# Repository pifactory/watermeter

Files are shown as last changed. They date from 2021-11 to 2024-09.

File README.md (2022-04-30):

# Smart Water Meter Sensor
 [][cc-by]

Design files for making inductive sensor for reading out smart water meters.

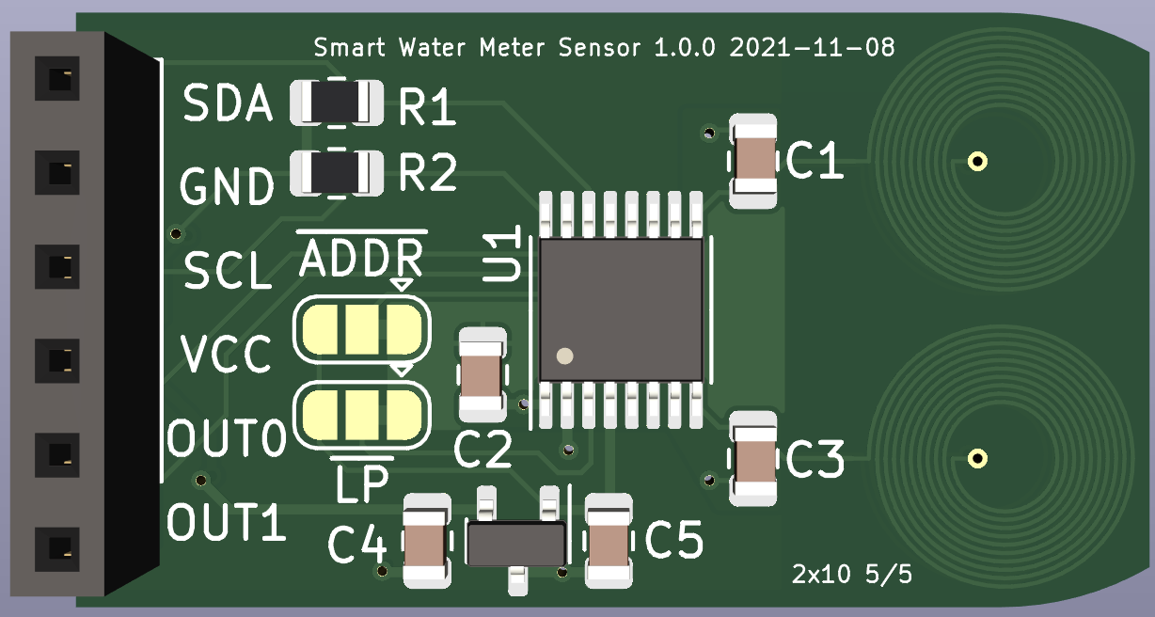
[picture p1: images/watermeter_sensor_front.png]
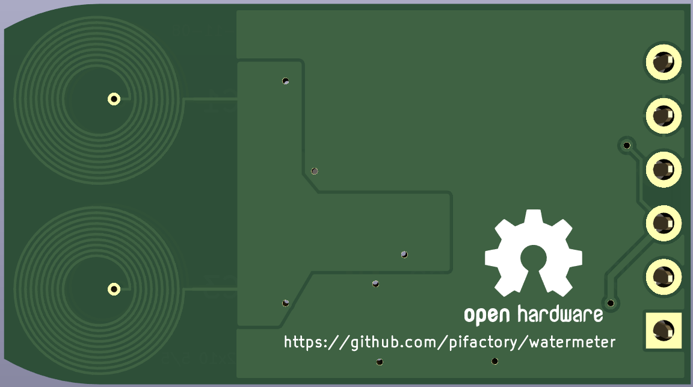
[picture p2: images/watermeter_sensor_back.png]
 

## Features

* 20 &mu;A in low-power mode (including microcontroller)
* Small footprint: 18mm x 32.5 mm, can be placed directly on the water meter glass
* Easy to use: inductive sensors are printed directly on the PCB
* Designed for wheel diameter of 18mm
* Includes 2 inductive sensors for reliable counting of the wheel turns

## How Smart Water Meter works

Many water meters are made 'smart-ready', ie they include a wheel under the glass
which makes 1 turn per liter. Half of the wheel contains some metal (copper) on it
which can be sensed by an inductive sensor.

Because of the costs water supply companies usually do not install smart reading device
on such meters, but some nerds among us are stubborn enough to design and install
their own reading device. Just to know how much water is used and be able to monitor it
with, say, a Home Assistant. It can be also used to detect leaks.

One inductive sensor is not enough for reliable readings. There are some corner
cases when the sensor will miss a turn of the wheel or count 1 turn 2 times. Think of it like
this: wheel can stop at any moment at any angle and then continue movement at any
time later on. During this stop environment can change significantly (temperature &
humidity) to fool the sensing circuit. On top of it, to save power, each inductive
sensor is scanned once in 800ms, ie there is no continous output from it. All in all,
2 inductive sensors allow to detect illogical readings and in many cases repair them.

For now here is just the sensor, controller is coming soon... I've made one for
Zigbee already and it runs on 2 AAA batteries.

Here is the photo of the first prototype:

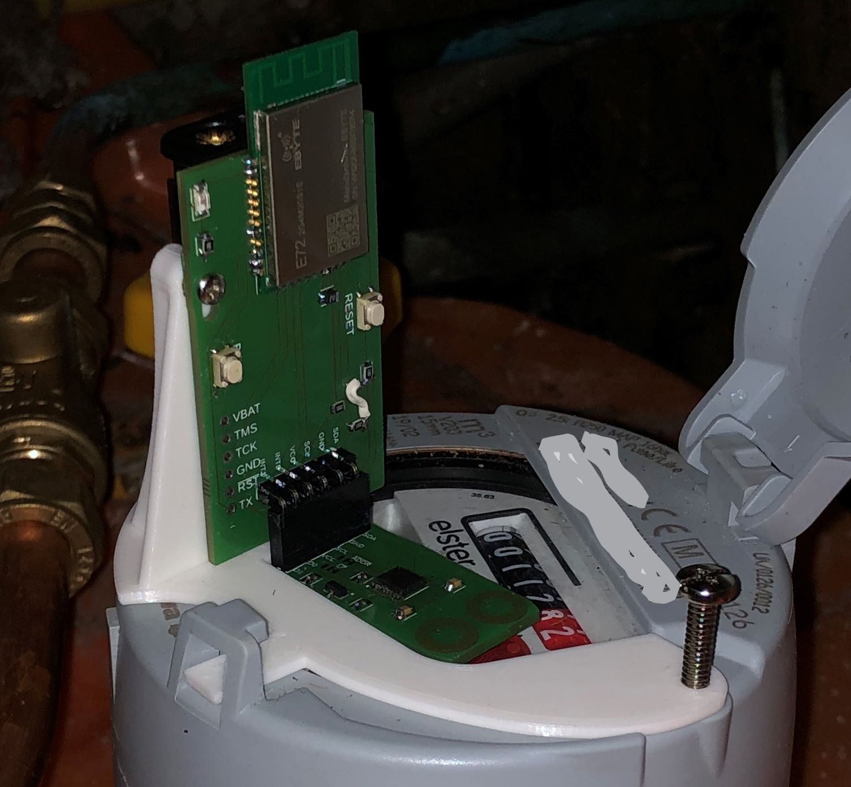
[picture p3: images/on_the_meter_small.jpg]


## How to use design files

I used KiCAD 6 to make the design. You will probably also want to install [kicad-goodies](https://github.com/pifactory/kicad-goodies) libraries, but this is not required.

A word about choosing a PCB shop. Inductive sensors on the PCB require as much as possible turns
on as little space possible. This means that the traces have to be as thin as possible and the
spacing between them has to be as small as possible. Also there is no copper around them +
geometry of the traces = you might get shorts between traces if you push it to the limit.

Most shops out there (including JLCPCB) claim to be able to produce 6 mils traces with 6 mils spacing
between them. I work with AISLER and they produce 5/5 mils boards for the same price,
so this design has 5/5 PCB coils. I've made 6/6 PCB coils available in 
[kicad-goodies](https://github.com/pifactory/kicad-goodies), you can try them if 5/5
coils will not work for you. AISLER will need just *.kicad_pcb file, no Gerber is needed there and therefore not provided in this repo.

## Zigbee Microcontroller

This repo has all you need to make a Zigbee microcontroller for the sensor:

* KiCAD 6 design files for the PCB (incl schematic)
* Compiled firmware
* Configuration file for Zigbee2MQTT

Microcontroller is based on EBYTE module with CC2652P.  

Firmware has following features:

* Low power, should work for years on 2 AAA batteries
* Water usage data is buffered for 5 minutes
* When parent connection is lost: try to rejoin every 5 minutes
* Transmit power is set to 14dBm, this should be enough to get signal in challenging RF situations and yet to not use too much battery

Because of a bug in TI software, rejoin period cannot be longer than 5 minutes. Also rejoin uses more power than standard data report, so try to avoid situations when device stays on for longer periods without a connection to the network (like days, weeks, months)

Operation with 2 buttons and 1 LED:
* Join new network: click BTN1
* Leave network: press BTN1 for at least 10 seconds and release the button (long click)
* Immediately send data (when part of the network): click BTN1
* Rejoin (when parent is lost): click BTN1
* RESET button restarts the device
* LED blink once device (re-)joins Zigbee network

### Zigbee2MQTT

Place provided `pifactory_watermeter.js` file in the same directory as `configuration.yaml` file.

Add these lines to `configuration.yaml` file:

```yaml
external_converters:
    pifactory_watermeter.js
```

Restart Zigbee2MQTT and join the device

## Holder

I've made a holder which fits my Elster water meter. Meter without sensor looks like this:

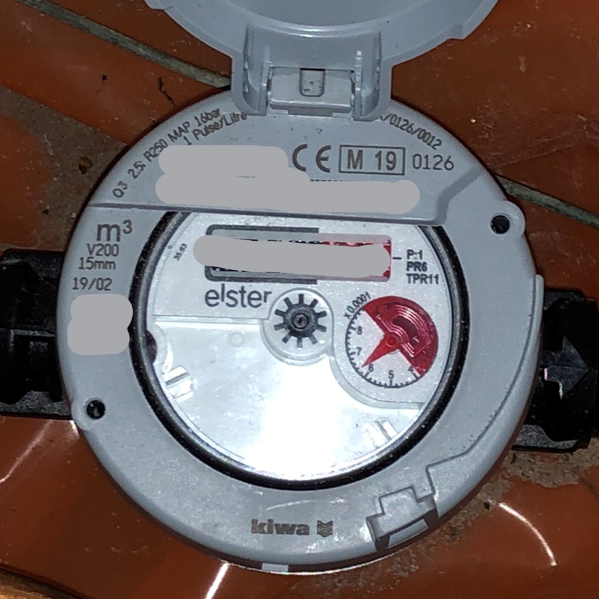
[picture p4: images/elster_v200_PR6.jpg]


I didn't tried the holder on any other meter, but I suspect it fits different models as well. Please share your meters/holders or contact me if you need help fitting this sensor to your meter.

---
This work is licensed under a
[Creative Commons Attribution 4.0 International License][cc-by].

[][cc-by]

[cc-by]: http://creativecommons.org/licenses/by/4.0/
[cc-by-image]: https://i.creativecommons.org/l/by/4.0/88x31.png
[cc-by-shield]: https://img.shields.io/badge/License-CC%20BY%204.0-lightgrey.svg

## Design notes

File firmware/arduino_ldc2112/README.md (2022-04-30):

# Example Arduino code for LDC2112 based water meter sensor

Small Platformio project to start making your own firmware for LDC2112 based water meter.

## This is just a demo

You have to add WiFi logic yourself and add data collection mechanism of choice (MQTT?) to connect it to your home automation platform.

## Known Issues

### GPIO interrupts do not trigger properly

Keep in mind that LDC2112 works from 1.8V and not 3.3V. This means that you get only 1.6-ish volts on interrupt lines coming from the chip. On most ESP-based boards I have in my possession this is not enough for reliable triggering of GPIO inputs.

There are 2 solutions:

*  Use i2c registers (like in this demo)
*  Make level translator `1.8V` --> `3.3V` (and enjoy `attachInterrupt(...)`)

### Sensor becomes blind when wheel stops under the coil for too long

LDC2112 is designed for inductive keyboard and has number of algorythms to reliably detect key press. One of them - baseline tracking. So, the chip detects rapid changes of inductance of the coil. When wheel stops or is moving too slowly, sensor can become 'blind'.

Best strategies to apply:
* Stop tracking baseline when the channel is active (wheel is under the coil)
* Change the speed of baseline tracking: slow for positive values, fast for negative
* Use both coils to detect movement. Baseline is tracked independently for each of them, so the chance that both become blind at the same time is low
* Define some mitigation measures once inconsistent triggering detected (coils trigger out of natural order):
  * Read status register (0x00) - this will clear TIMEOUT flag, or any other error flags
  * Temporarily enable full baseline tracking on misbehaving coil - may be it is just way off environment changes?

I advice also logging STATUS, OUT, DATA0 and DATA1 registers (0x00 - 0x05) when debugging this issue. Might give new insights on how further improve the algorythm.

### Reading is not 100% reliable

I've got it as far as 0.1% error of the actual value read on the meter itself, this is after 6 months. By no means statistically significant, just give you an idea.

That said, water meter reading via inductive sensor is not 100% reliable by design. Wheel on the water meter can be as slow or as fast as:
* I have 20l/min capacity on my home water supply, so full turn takes at least 3 seconds
* leaking water: wheel moves as slowly as you can imagine ([Parmenides](https://en.wikipedia.org/wiki/Philosophy_of_motion))
* No movement

The latter 2 are difficult to distinguish from slowly changing environment conditions, like temperature and humidity. What sensor sees is only slow change of induction, but there is no way to see why it is changing.

Both scan rate and sensitivity should not allow for undetected turns. The challenge here is that the wheel can stop at **any** position and the coils are sensed only so often by the chip. So, we can get stroboscope effect: like there is a movement, but it is not detected, because the wheel is moving too fast through the coil sensing zone and stops in the blind zone.

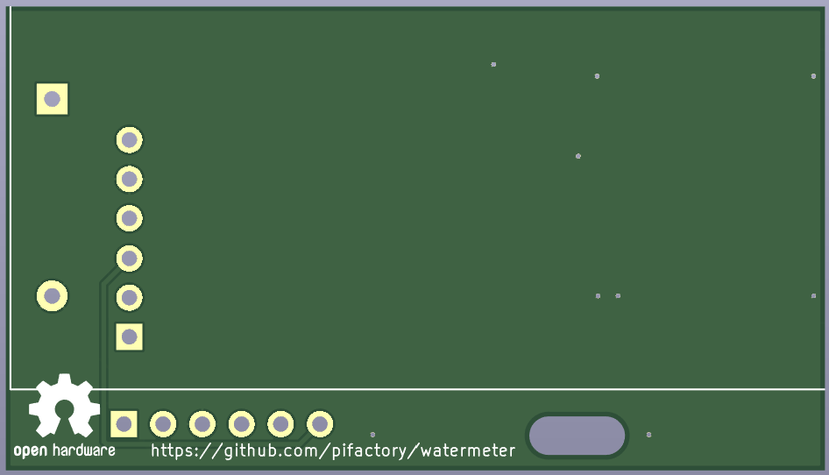
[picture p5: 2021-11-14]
images/watermeter_zigbee_mc_back.png

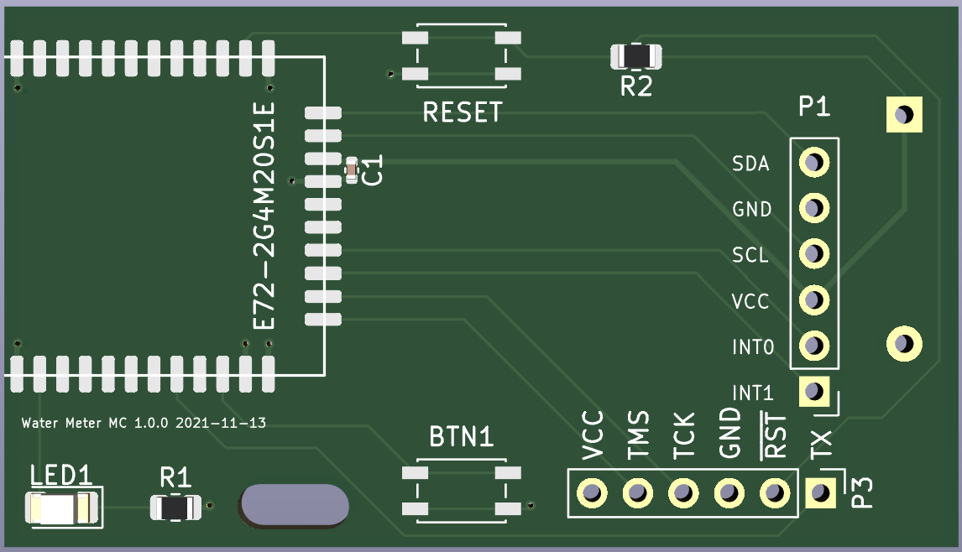
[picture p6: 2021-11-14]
images/watermeter_zigbee_mc_front.png

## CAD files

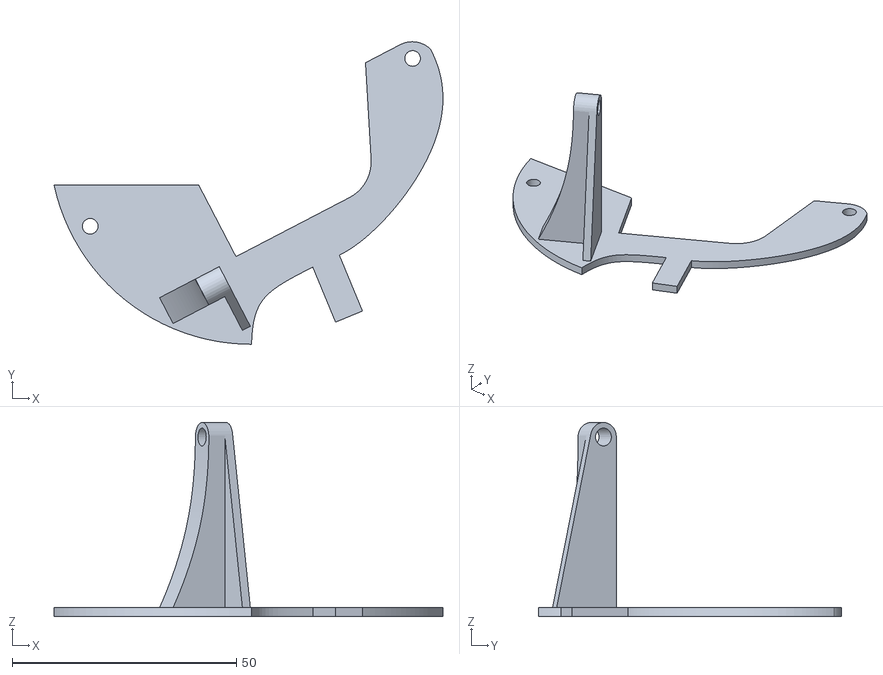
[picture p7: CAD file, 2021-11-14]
3dprints/holder_elster200.stl
86.7 x 67.4 x 43.2

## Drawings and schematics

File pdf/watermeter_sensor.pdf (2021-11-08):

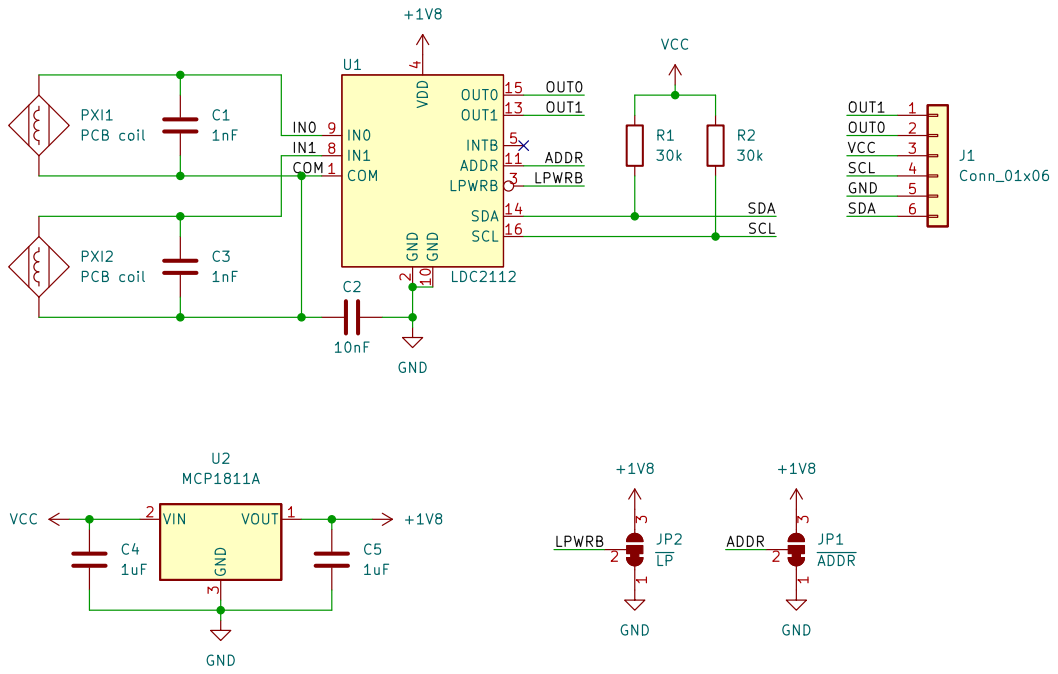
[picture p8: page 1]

File: watermeter_sensor.kicad_sch Sheet: / Copyright (c) 2021 Alexander Dvorkovyy This work is licensed under a Creative Commons Attribution 4.0 International License.

Id: 1/1 Title: Smart Water Meter Sensor

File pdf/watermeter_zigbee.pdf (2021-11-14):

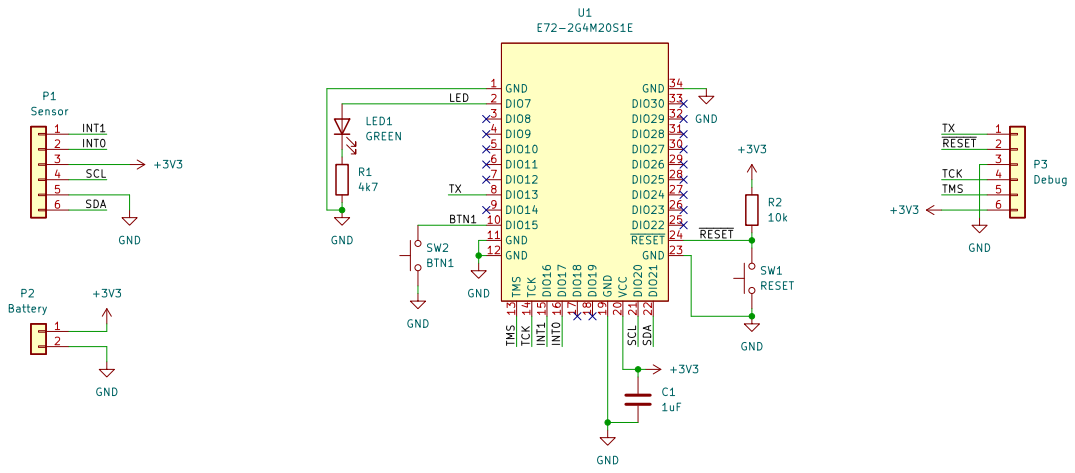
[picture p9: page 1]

Id: 1/1 Title: Water Meter Zigbee Microcontroller

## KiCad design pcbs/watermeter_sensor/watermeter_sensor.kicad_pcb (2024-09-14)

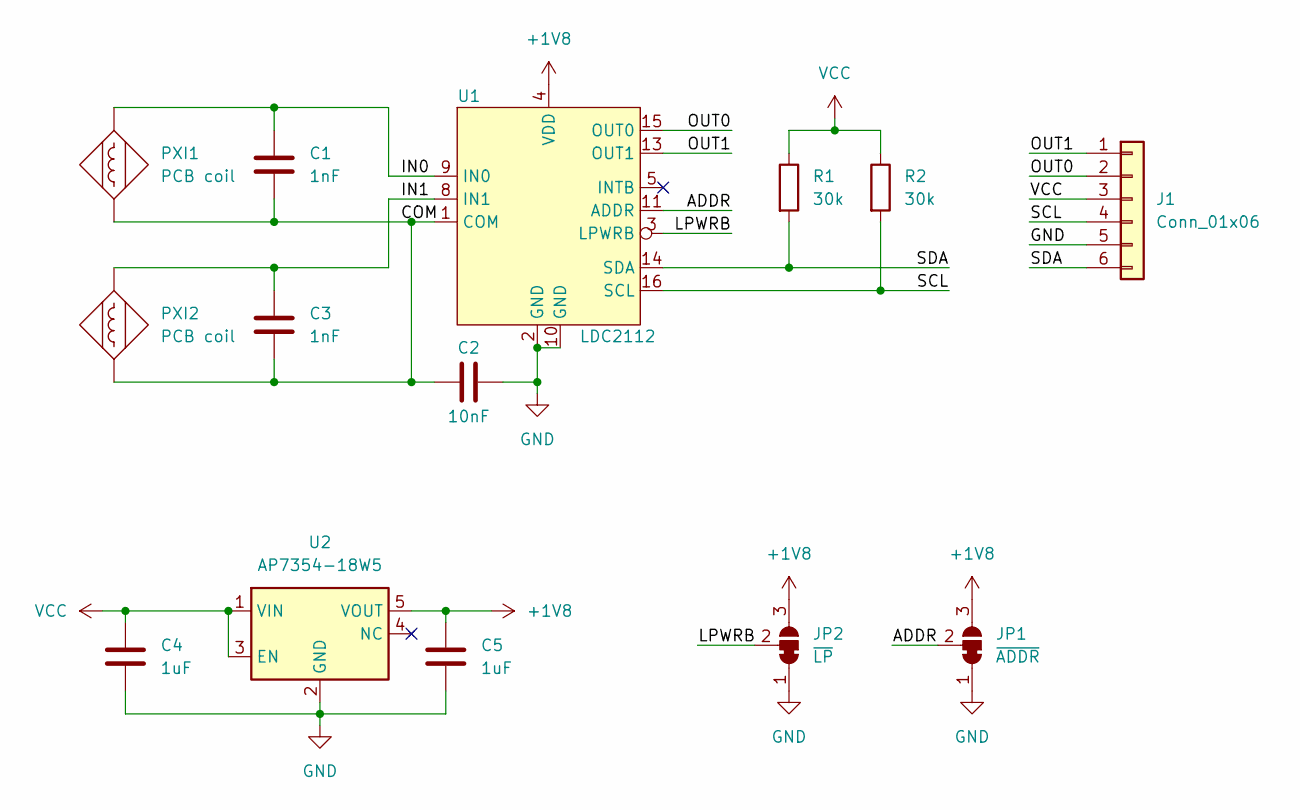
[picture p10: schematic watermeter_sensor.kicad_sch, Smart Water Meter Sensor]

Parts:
C1, C3: 1nF; C_0805_2012Metric
C2: 10nF; C_0805_2012Metric
C4, C5: 1uF; C_0603_1608Metric
J1: Conn_01x06; PinSocket_1x06_P2.54mm_Vertical
JP1: ~{ADDR}; SolderJumper-3_P1.3mm_Bridged12_RoundedPad1.0x1.5mm
JP2: ~{LP}; SolderJumper-3_P1.3mm_Bridged12_RoundedPad1.0x1.5mm
PXI1, PXI2: PCB coil; pcb_coil_8mm_2Lx10T_5-5
R1, R2: 30k; R_0603_1608Metric
U1: LDC2112; TSSOP-16_4.4x5mm_P0.65mm
U2: AP7354-18W5; TSOT-23-5

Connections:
+1V8: C5.1, JP1.3 (B), JP2.3 (B), U1.4 (VDD), U2.5 (VOUT)
/ADDR: JP1.2 (C), U1.11 (ADDR)
/COM: C1.2, C2.1, C3.2, PXI1.1, PXI2.1, U1.1 (COM)
/IN0: C1.1, PXI1.2, U1.9 (IN0)
/IN1: C3.1, PXI2.2, U1.8 (IN1)
/LPWRB: JP2.2 (C), U1.3 (LPWRB)
/OUT0: J1.2, U1.15 (OUT0)
/OUT1: J1.1, U1.13 (OUT1)
/SCL: J1.4, R2.2, U1.16 (SCL)
/SDA: J1.6, R1.2, U1.14 (SDA)
GND: C2.2, C4.2, C5.2, J1.5, JP1.1 (A), JP2.1 (A), U1.2 (GND), U1.10 (GND), U2.2 (GND)
VCC: C4.1, J1.3, R1.1, R2.1, U2.1 (VIN), U2.3 (EN)

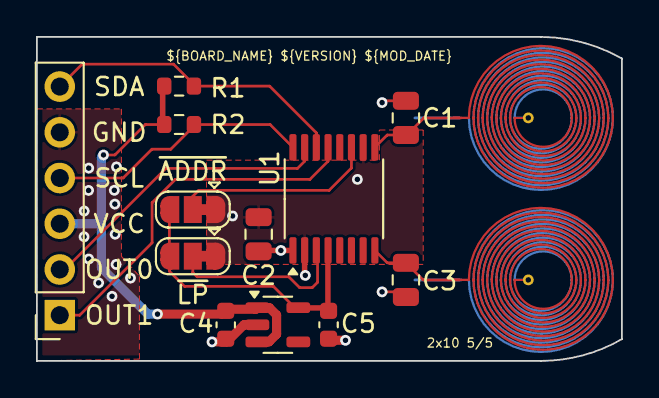
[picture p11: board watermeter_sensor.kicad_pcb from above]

Board: 2 copper layers, 32.5 x 18.0 mm, 14 parts (0 on the bottom side), 12 nets.

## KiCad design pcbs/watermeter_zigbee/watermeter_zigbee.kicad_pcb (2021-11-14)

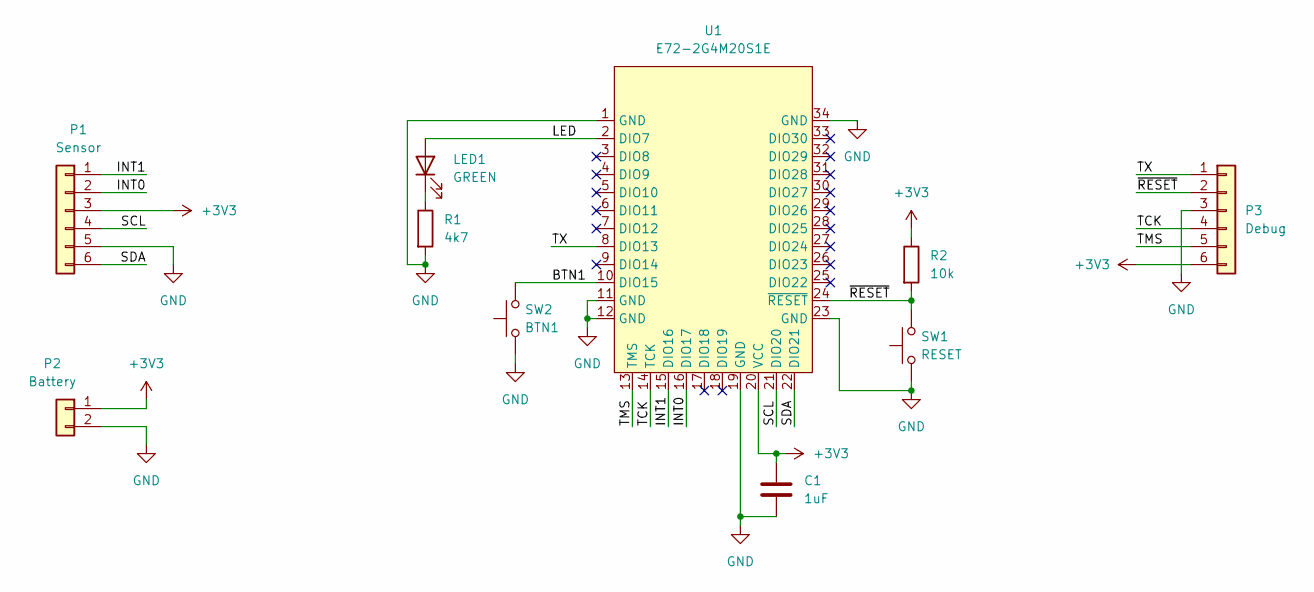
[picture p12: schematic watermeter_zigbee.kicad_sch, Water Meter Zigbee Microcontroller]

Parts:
C1: 1uF; C_0402_1005Metric
LED1: GREEN; LED_1206_3216Metric
P1: Sensor; PinHeader_1x06_P2.54mm_Vertical
P2: Battery; BatteryHolder_Keystone_2468_2xAAA
P3: Debug; PinHeader_1x06_P2.54mm_Vertical
R1: 4k7; R_0805_2012Metric
R2: 10k; R_0805_2012Metric
SW1: RESET; SW_SPST_EVQP2
SW2: BTN1; SW_SPST_EVQP2
U1: E72-2G4M20S1E

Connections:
+3V3: C1.1, P1.3, P2.1, P3.6, R2.1, U1.20 (VCC)
/BTN1: SW2.2, U1.10 (DIO15)
/INT0: P1.2, U1.16 (DIO17)
/INT1: P1.1, U1.15 (DIO16)
/LED: LED1.2 (A), U1.2 (DIO7)
/SCL: P1.4, U1.21 (DIO20)
/SDA: P1.6, U1.22 (DIO21)
/TCK: P3.4, U1.14 (TCK)
/TMS: P3.5, U1.13 (TMS)
/TX: P3.1, U1.8 (DIO13)
/~RESET: P3.2, R2.2, SW1.2, U1.24 (~RESET)
GND: C1.2, P1.5, P2.2, P3.3, R1.2, SW1.1, SW2.1, U1.1 (GND), U1.11 (GND), U1.12 (GND), U1.19 (GND), U1.23 (GND), U1.34 (GND)
unnamed: LED1.1 (K), R1.1

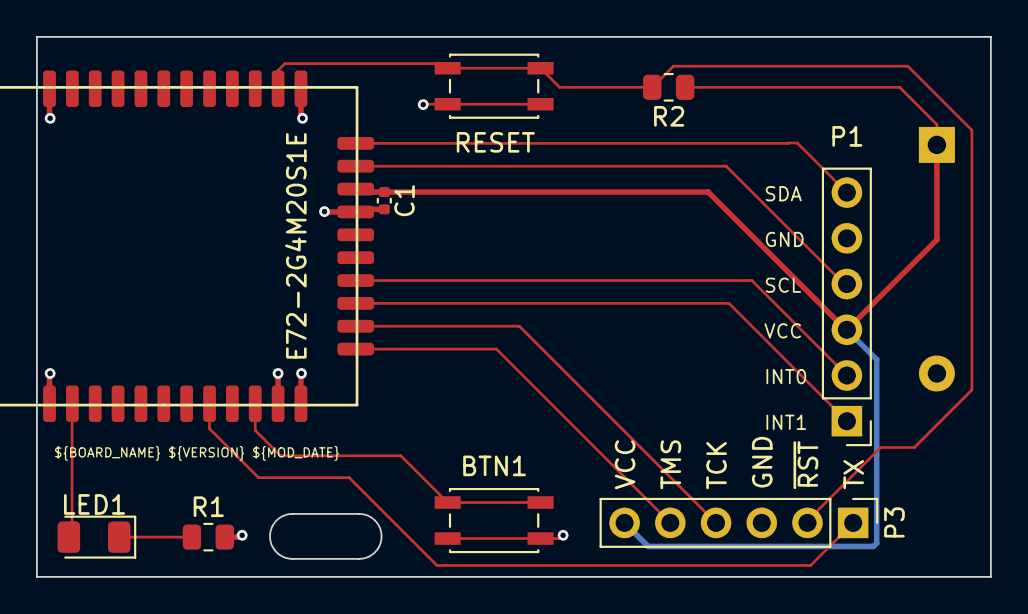
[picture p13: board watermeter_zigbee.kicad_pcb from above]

Board: 2 copper layers, 53.0 x 30.0 mm, 10 parts (1 on the bottom side), 13 nets.

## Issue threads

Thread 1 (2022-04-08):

ldc2112 register configuration query

JuanRosadio98, 2022-04-08:
Hello

I have been successful in getting the sensor to detect a metal.
But I have problems when the metal object stays on the sensor, because after a while the output OUT0 of the sensor returns to HIGH, stopping detecting the metal.
OUT0 output of the sensor returns to HIGH, not detecting the metal.
According to the datasheet there is a maximum continuous activation allowed which is ~50 seconds.
so I paused the line tracking through the register BTPAUSE_MAXWIN -> B00110000,
this makes that after the time of continuous activation the OUT0 output keeps the LOW state of detection,
but the sensor stops working correctly and no longer differentiates between the presence or absence of the metal object.

how did you configure the registers of the LDC2112 chip, so that it works correctly ?

advorkovyy, 2022-04-08:
It took me a while to figure out the right settings, important is that algorithm uses both sensors and accounts for temporary blindes of one of them. It doesn't happen that often. There is no way to guarantee 100% correctness of the counter, there is always a possibility for an error, because of slow changes in the environment. You simply do not know why it is happening from physical process: either because the metal moves or, for example, humidity/temperature changes.

I've chosen parameters which seems to producing very little if any error over weeks of observation.

advorkovyy, 2022-04-09:
Guys, which controllers are you using? And is it battery-based or mains power? How much power budget is available? May be I will port the firmware. Settings are working together with the algorithm, it's not that easy to explain everything or just give you the settings.

One sensor going blind is normal, it restores back quickly:
```
// Set x8 faster baseline tracking when data is negative
i2cDeviceWriteReg8(LDC2112_I2C_ADDR, 0x25, 0x06);
i2cDeviceWriteReg8(LDC2112_I2C_ADDR, 0x28, 0x70);
```

As I said, your counting algorithm has to be able to account for temporary blindness of one of the sensors:
```
if (interrupt & TRIGGER_INT0) {
    output.counter += 1;
} else if (interrupt & TRIGGER_INT1) {
    if (state.lastInterrupt & TRIGGER_INT1) {
        // missed signal from the first sensor, OUT0
        output.counter += 1;
    }
}
state.lastInterrupt = interrupt;
```

JuanRosadio98, 2022-04-09:
I am working with an esp32 in arduino and an 18650 battery. I had tried with several configurations of the registers without success.  Thanks I will try that configuration and the algorithm that you propose.  I suppose that if I am working the ldc2112 in LowPower mode, I have to activate the operation of the second coil?

advorkovyy, 2022-04-09:
yes, you need both coils.

What I also did to save power - to send data once every 15min, only if the counter has been updated. CC2652 variations have low-power core, I've implemented counting algorithm there. Power-hungry M4 core is waken up only when there is something to send. ZigBee is very efficient protocol for that, so the whole cycle is short.

It is possible to write working code for Arduino on ESP32, but it will be more power consuming than CC2652. So, I would expect mains power, if possible. Having rechargeable battery is an option too, given the board is designed for long operation on the battery. You can expect it working like months then before you have to recharge or replace the battery.

I have very good experience with Lora E5 module on another project, but it requires LoraWAN gateway somewhere nearby. In theory it consumes more power, but in practice it outperforms my other ZigBee projects on battery longevity.

advorkovyy, 2022-04-30:
Just added [Arduino example](https://github.com/pifactory/watermeter/tree/master/firmware/arduino_ldc2112) Ported it from my CC2652P firmware. It is not complete replica, but all important bits are mentioned there.

@JuanRosadio98 @markoAntonio1692 would you care to tell more about your projects? You can contact me on https://hackaday.io/advorkovyy

Well, anybody who cares to talk about what are you doing with this sensor can contact me, of course. I am very much interested :)

markoAntonio1692, 2022-05-05:
Hola Alexander un gusto saludarte,
Disculpa que te hable en español se me hace más sencillo explicarlo así,
creo que podrías traducirlo al igual que yo lo hago con  tu mensaje. Soy de
Lima - Peru, quizás podamos intercambiar información acerca del sensor,
comentar nuestras experiencias con él y generar inteligencia colectiva.
Tengo un proyecto para una empresa que trata de digitalización para
medidores de tipo Zenner y Elster. Actualmente cuento con un banco de
pruebas  donde he acondicionado el sensor ldc2112 con un transmisor Sigfox
he hecho muchas pruebas y hemos logrado hacer que el sensor funcione bien
(te podría dar mas detalles de ello y la configuración que uso).
Pero ahora me he encontrado con un nuevo problema, cuando hago que la rueda
del medidor gire lento, al parecer no logra detectar, estoy revisando si es
un problema de electrónica o probar nuevas configuraciones...

Si  gustas podemos hablar por whatsapp o telegram para comunicarnos mas
rapido, te adjuntare algunas fotos de mi banco de pruebas.
Saludos.

Marco A. Caballero Moreno.
[image: photo1651776798 (3).jpeg]
[image: photo1651776798 (2).jpeg]
[image: photo1651776798 (1).jpeg]
[image: photo1651776798.jpeg]

El sáb, 30 abr 2022 a las 6:13, Alexander Dvorkovyy (<
***@***.***>) escribió:

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

--
Saludos Cordiales.

*Marko A. Caballero Moreno*
*Ing. Electrónico y Telecomunicaciones*
*+51 998 481 553*

*"La mejor herencia que podemos dejarle a nuestros hijos es: Amor,
conocimiento y un planeta limpio en el que puedan vivir"*
[image: Resultado de imagen para piense bien antes de imprimir]

advorkovyy, 2022-05-05:
You say you have a problem when wheel moves slowly - how slowly then? How long does one turn last? By design this sensor will stop detecting movement at some low speed. For my purposes it is not a problem.

And what do you write to 0x13 (LP_BASE_INC) register? Default value is 5, I am using 4. You might try further reduce it. It can be that it stops tracking baseline at all and when condition changes, sensor will not detect any movement at all. I didn't investigated it.

Unfortunately, pictures didn't made it here

markoAntonio1692, 2022-05-05:
Hola Alexander
Te envio la configuración que empleo actualmente.
-Solo uso una bobina y configure el pin de bajo consumo a tierra para
ahorrar al máximo energía.
- Solo me interesan los flancos de subida por lo que si la bobina queda
encima de la parte metálica, no me interesa si el estado cambia o se
mantiene, solo me interesa que el estado cambie cuando la rueda ya cruzó a
la bobina.

Saludos

El jue, 5 may 2022 a las 14:37, Alexander Dvorkovyy (<
***@***.***>) escribió:

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

--
Saludos Cordiales.

*Marko A. Caballero Moreno*
*Ing. Electrónico y Telecomunicaciones*
*+51 998 481 553*

*"La mejor herencia que podemos dejarle a nuestros hijos es: Amor,
conocimiento y un planeta limpio en el que puedan vivir"*
[image: Resultado de imagen para piense bien antes de imprimir]

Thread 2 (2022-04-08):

The sensor stops working properly when it is on the metal part for a long time

markoAntonio1692, 2022-04-08:
Hi,
I also follow your project, and I have the problem that when the sensor is positioned in the metal part for a long time, it returns to state 1 and it is as if it lost the detection range. How did you do to correct that error? I would appreciate it if you could upload your algorithm or tell me how to configure the sensor registers....By the way, a very good project. I congratulate you, you have earned my admiration. Greetings

advorkovyy, 2022-04-09:
Duplicate of issue #1

Closed 2022-04-09.

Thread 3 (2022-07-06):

reverse count

daeynasvistas, 2022-07-06:
this is great!! love your sensor. I was able to detect movement and count with i2c

what about reverse count?  in your example if the meter reverse the water flow .. the count are still adding.
i think it will be easy to detect reverse count with 2 coil ?

did someone have try to do that?

advorkovyy, 2022-07-06:
I really had usual household water meter in mind, which a) can't turn in reverse; b) even very slow water flow gives decent amount of spins for LDC2112 to be detected.

You could try to detect reverse count if you place the coils on the side of the spinning wheel, like in this application note:
https://www.ti.com/lit/an/slaa639/slaa639.pdf

I didn't tried it.

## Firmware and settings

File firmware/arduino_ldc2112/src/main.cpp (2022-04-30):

#include <Arduino.h>
#include <Wire.h>
#include <arduino_ldc2112.h>

static uint16_t counter = 0;
static uint16_t errors = 0;
static uint8_t out_prev = 0;
static LDC2112Out lastInterrupt = LDC2112_OUT0;
static LDC2112State ldc2112_state;

static void IRAM_ATTR sensor_int0()
{
  counter++;
  lastInterrupt = LDC2112_OUT0;
}
static void IRAM_ATTR sensor_int1()
{
  if (lastInterrupt == LDC2112_OUT1)
  {
    // missed signal from the first channel
    errors++;
    counter++;
  }
  lastInterrupt = LDC2112_OUT1;
}

static bool isTriggered(LDC2112Out out_)
{
  bool prevState = out_prev & out_;
  bool currentState = ldc2112_state.out & out_;

  return !prevState && currentState;
}

void setup()
{
  Serial.begin(115200);
  Wire.begin(I2C_SDA, I2C_SCL);
  ldc2112_begin(&Wire);
}

void loop()
{
  ldc2112_read(&ldc2112_state);
  if (isTriggered(LDC2112_OUT0))
  {
    sensor_int0();
  }
  if (isTriggered(LDC2112_OUT1))
  {
    sensor_int1();
  }
  out_prev = ldc2112_state.out;

  static uint_fast8_t i = 0;
  if (i == 0)
  {
    Serial.printf("state=%x out=%x counter=%u, errors=%u, data0=%d, data1=%d\n",
                  ldc2112_state.status,
                  ldc2112_state.out,
                  counter,
                  errors,
                  ldc2112_state.data0,
                  ldc2112_state.data1);
  }
  i = (i + 1) % 2;

  delay(500);
}

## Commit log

2021-11-14 Add Zigbee Microcontroller design files
    [holder_elster200.stl, watermeter_sensor.kicad_pcb, watermeter_sensor.kicad_sch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]
2022-04-30 Add Arduino example
2024-09-14 Watermeter v1.1 (#6)
    * Update Arduino library
    * PCB Changes v1.1:
    - changed LDO
    - some footprints changed to 0603
    [watermeter_sensor.kicad_pcb, watermeter_sensor.kicad_sch]

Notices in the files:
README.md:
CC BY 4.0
